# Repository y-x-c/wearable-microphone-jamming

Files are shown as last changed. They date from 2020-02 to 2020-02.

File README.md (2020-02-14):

# Wearable Microphone Jamming

<p align="center">teaser</p>

Repository for our paper [Wearable Microphone Jamming](http://sandlab.cs.uchicago.edu/jammer/).

This repo provides simulation source code, hardware design, firmware and schematics to replicate our results and prototypes in the paper.

## Structure of this repo

`simulation` contains MATLAB simulation code
- `doc`: documentation for the simulator
- `simulation.m`: main file of the simulator

`jammer_hardware_source` contains all sources related to hardware
- `3d_printing_models`: 3D model of our final prototype
- `arduino_code`: code for ATMEGA32U4 microprocessor, which controlls an AD9833 signal generator

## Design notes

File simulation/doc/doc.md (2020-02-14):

# Simulation Algorithm Documentation

[TOC]

## Simulation 

Details of our simulation can be found in the paper. Here, we expand and document its code, which we plan to release for future researchers to build upon.  

### Overview

Generally speaking, our simulation is a simple 3D ray tracing engine with a transducer-array placed at the origin (x=0,y=0,z=0). For a 3D location $p$, the mean sound pressure in a period of time, $\overline{P(p)}$, can be calculated as:

$$
\overline{P(p)} = \sqrt{ \frac{1}{|T|} \cdot \sum_{t \in T}{P_{t}(p)^2}}
$$

We sampled $0.4s$ with $0.013573s$ time step, which was intentionally chosen because it can not be divided by $1/fs$ (where $fs=25kHz$ in our case). $0.4s$ was chosen because it matches the speech rate in a conversation.

The total far field generated by all the transducers at time $t$ can be computed as the summation of the contribution of each indidvidual transducer
$$
P_t(p) = \sum_{s \in S}{P_{t,s}(p)}
$$

### Calculating $P_{t,s}(p)$

$$
P_{s,t}(p) = P_{ref} \cdot gain \cdot
               f_s(t - \frac{d(p, p_s)}{c_0})
$$

where $gain$ represents how the signal attenuate; $d(p, p_s)$ is the distance between the transducer and the point, and $f_s(t)$ represents the signal transmitted by a transducer $s$ at time $t$.

$P_{ref}$ is the reference pressure at 1m. We first measured sound pressure level at 1m and then use the following equation to calculate $P_{ref}$:

$$
P_{ref} = 10^{(L_A / 20)} * 0.00002\ Pa
$$

Here, $L_A=68dBA$ and $P_{ref} = 0.05024 \ Pa$.

### Calculating $gain$

$gain $ consists of 2 parts: (1) directivity of the transducer, (2) propagation loss with distance.

$$
gain = loss_{directivity} * loss_{distance}
$$

#### (1) Transducer directivity loss: $loss_{directivity}$

We model transducers as a piston source:

$$
loss_{directivity} = \frac{2 \cdot J_1(k \cdot r \cdot sin \theta)}{k \cdot r \cdot sin \theta}
$$

We also compared the directivity pattern from the datasheet with the one we modeled: (blue line means the modeled pattern, red line is the one from datasheet)

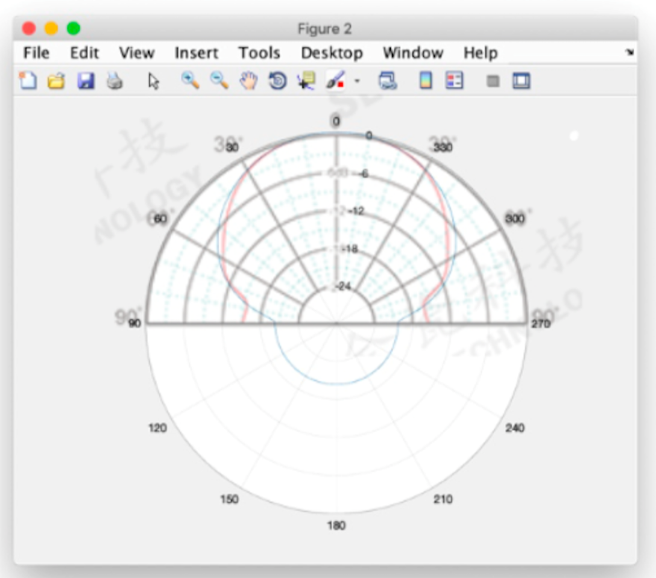
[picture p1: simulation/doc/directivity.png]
directivity


*For 90 to 270 degree, the original pattern is not available; we simply repeat the value at 90 degree at this range.*

#### (2) Propagation loss with distance: $loss_{distance}$

The propagation loss can be calculated as
$$
loss_{distance} = \frac{1}{d(p, p_s)}
$$

### Simulating rotation of a transducer array

Lastly, the previous explanation is how we simulate a static array. To add movement (e.g., rotation) to a transducer array, we do as follows: at each simulation step, a new position and orientation of a transducer is updated before calculating its resulting signal amplitude. For any given 3D location and transducer, its new position (and rotation) may increase or decrease $gain$, resulting in a stronger or weaker power. This rotation and its effects is how movement of a tranducer might assist in reducing blind spots.

## Running the simulator

To run our simulator, load our ``simulation_v3.m`` in MatLab (we used R2017b) and run it.

#### Exemplary simulation 

```matlab
xy_res = 0.002;

%%% To replicate the figures shown in nour simulation section in our paper, simply choose one of the options below (and comment the others)

%%% fig a 
num_sources = 1; rotate_angle = 0; planar_layout = 1;
simulation_v4;
%%% fig b 
num_sources = 1; rotate_angle = 0; planar_layout = 0;
simulation_v4;
%%% fig c 
num_sources = 9; rotate_angle = 0; planar_layout = 0;
simulation_v4;
%%% fig d 
num_sources = 1; rotate_angle = 15; planar_layout = 0;
simulation_v4;
```

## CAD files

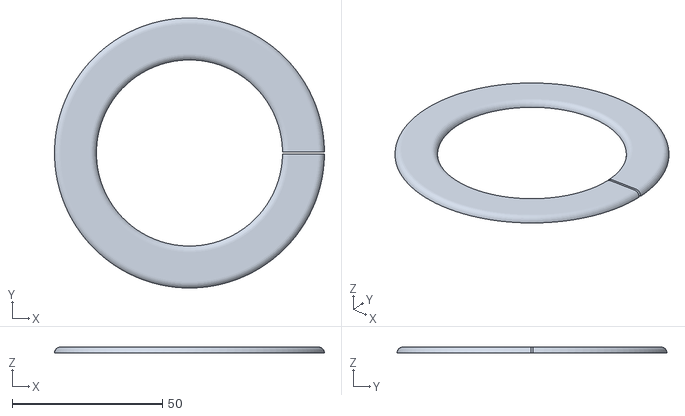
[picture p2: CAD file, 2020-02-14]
jammer_hardware_source/3d_printing_models/side_cap.stl
90.0 x 90.0 x 2.00

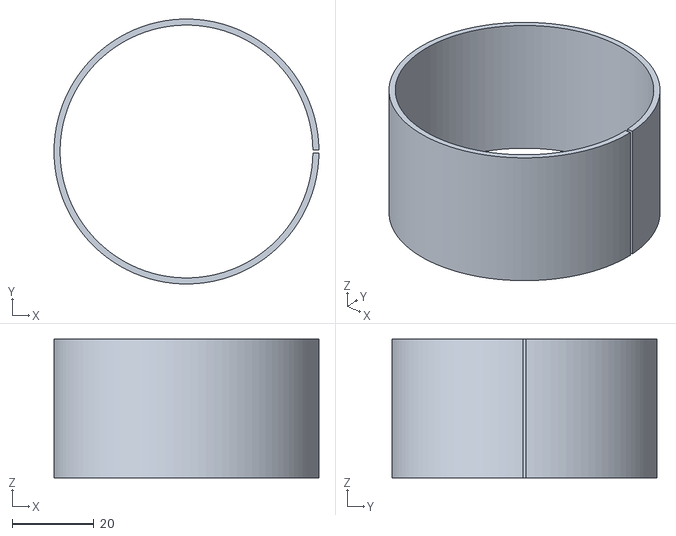
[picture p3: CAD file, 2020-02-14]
jammer_hardware_source/3d_printing_models/inner_ring.stl
65.0 x 65.0 x 34.0

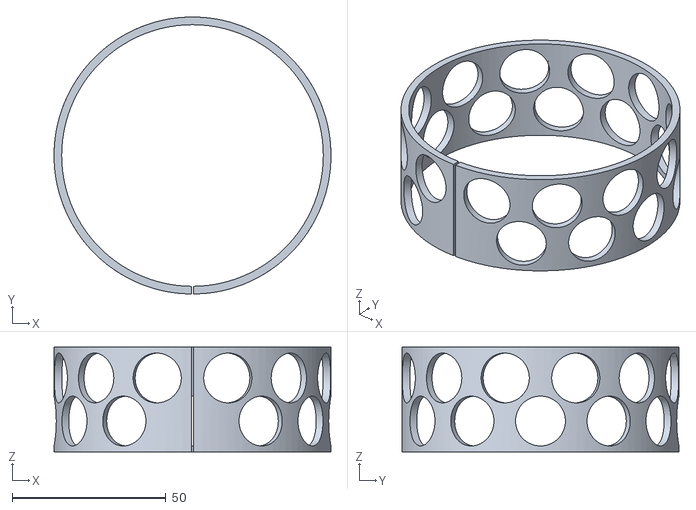
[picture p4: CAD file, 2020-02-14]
jammer_hardware_source/3d_printing_models/outer_ring.stl
90.0 x 90.0 x 34.0

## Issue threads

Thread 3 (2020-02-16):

About the hardware connection

SCWhite, 2020-02-16:
HI,
this project is amazing, good job.

Is there a chance showing the hardware connection ?
or how do the wave generator and ultrasonic transducer connect to each other?

It's truly fascinating work.

y-x-c, 2020-02-16:
Thanks!

The wave generator is connected to a 3w amplifier, and transducers are connected to the amplifier.
For the connection between the microprocessor and the wave generator, please refer to https://github.com/y-x-c/wearable-microphone-jamming/blob/1fd86c55f8f5f8a2b8336bd066d6a1fbe3146ac1/jammer_hardware_source/arduino_code/wearable_microphone_jammer/wea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

wissal12345, 2020-02-18:
merci

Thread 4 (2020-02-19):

Where can i buy nu25c16t?

vovo255, 2020-02-19:
Where can i buy nu25c16t? I rummaged through the entire Internet, I can not find anywhere. Where did you buy them?

fritztoch, 2020-02-19:
I believe there is an equivalent part TCRT16-40 which is available on AliExpress and Amazon.

vovo255, 2020-02-19:
But is it 40 kHz? This transmitter will suit you? You have 25 kHz.

SCWhite, 2020-02-20:
@vovo255
HI, I can confirm that 40kHz works jamming the mic (not sure the performance compare with 25kHz).
but you may need to change the code and some component.
may be try TCT25-16 ?

ozw1z5rd, 2020-02-23:
> Where can i buy nu25c16t? I rummaged through the entire Internet, I can not find anywhere. Where did you buy them?

You find them on eBay https://www.ebay.com/itm/16MM-Ultrasonic-Sensor-Probe-Transceiver-Receiver-TCT40-16T-R-NU25C16T-1-/272708217220

pracdaske, 2020-03-02:
@SCWhite I'm planning on recreate the device with a 40Khz transmitter. Which are those changes on the code that you mention to confirm that it worked with this frequencies.

T-vK, 2020-03-02:
That ebay offer is extremely expensive and includes the R-variant which is basically a microphone rather than a speaker. You'd pay like $63 for 23 of those.
You find much better offers on aliexpress. See #6

Scanboostar, 2020-05-11:
I found these:
https://nl.aliexpress.com/item/4000760514545.html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,searchweb201602_,searchweb201603_

pulpon6, 2023-04-20:
transmitter, receiver or transceiver 25Khz?

SCWhite, 2023-04-21:
in this case, you will just be using "transmit"
so transmitter and transceiver  should both work.

pulpon6, 2023-04-24:
And where can I buy nu25c16t ?

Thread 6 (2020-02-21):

Metrials and wiring all it up

digilander98, 2020-02-21:
Hi, is possible to have needed materials list amd wiring schematics?

Thabk you so much!

T-vK, 2020-02-25:
I've spent a lot of time on trying to figure out the exact hardware that was used and here is what i got so far:

1x [AD9833 DDS Signal Generator Module](https://www.aliexpress.com/item/33058314041.html)
23x [NU25C16T-1 aka TCT40-16T](https://www.aliexpress.com/item/32258563531.html)
1x [PAM8403 Mini Power Amplifier Board 3Wx2 (3-5.5V 4Ω)](https://www.droking.com/PAM8403-Power-amplifier-circuit-Board-Small-Audio-Amplifier-3W-3W-Digital-Amplifier-Board-Support-USB-Power-Supply)
1x [Adafruit Pro Trinket  (5V ATMEGA32U4)](https://www.adafruit.com/product/2000)
1x [500mAh 3.7V LiPo](https://www.aliexpress.com/item/33019024577.html) (seems close, but is not exactly the same)
1x [3.7v to 5v step up converter](https://www.aliexpress.com/item/32635991770.html) (seems close, but probably not the same)
1x [push button](https://www.aliexpress.com/item/33025135423.html) (The one with the blue tip; not 100% sure if it's the same)
1x blue LED with 220Ω resistor (not sure as you can only see the blue light in the video)

I think there's also a charging circuit and a charging port that hasn't been mentioned. At least it looks like there is something like a micro USB port in the video.
The charging circuit could be [something like this](https://www.aliexpress.com/item/32946628662.html).
But I'd probably ditch the step up converter for a [2 in 1 board like this](https://www.aliexpress.com/item/32819047141.html) that does both charging and stepping up to 5V. To save even more space you could desolder the USB A port.
Finally I would consider swapping the very pricey Adafruit Trinket for an [Arduino Micro clone](https://www.aliexpress.com/item/32768308647.html).

It would be great to have input from @y-x-c on all this because if we don't get the exact same components, they may not fit into the 3D printed enclosure. Thanks a lot for this awesome work btw!

digilander98, 2020-02-26:
Thank you sir

pracdaske, 2020-03-04:
@T-vK thanks a lot, I managed to get some modules that you listed as alternatives.

If you can could you provide some wiring schematics insights please

T-vK, 2020-03-04:
Once my parts arrive, I'll figure out how to wire them up and post my results here. But looking at the current situation in China, it may take more than a month until I receive my orders...

digilander98, 2020-03-04:
Why don t use an arduino nano clone?

digilander98, 2020-03-04:
And what about this:
https://a.aliexpress.com/_BOV2vj

SCWhite, 2020-03-05:
@T-vK
HI, I have a little question about
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

TCT40-16T have center frequency at 40kHz (on data sheet)
NU25C16T have center frequency at 25kHz

I doubt this two can be replace from each other (?)

I'm not a electronics expert, but I make some test on 40kHz transducer from a ultrasonic sensor
and it works fine to jam the microphone (with limit range about 10cm)

may be 40kHz doesn't have the same effect with 25kHz
 or may need to change the code from the project.

T-vK, 2020-03-05:
@digilanger98 I think the Arduino Micro clone is closer to the Trinket and I prefer micro USB over mini USB. Besides that, according to the paper the code was written for the ATMEGA32U, so it may not work on the nano.
What do you mean by "what about this"? It's the same board I linked to in my post, just a few cents cheaper.

@SCWhite I'm assuming they are the same because of offers like this:  https://www.ebay.com/itm/272708217220

But I could be wrong, that's why I was asking @y-x-c for input.

At what volume did you get a 10cm range btw? I think in the paper it was mentioned that it was running at almost 100 decibels.

digilander98, 2020-03-05:
For the arduino i think that the code is small and get right ports if different from the trinket will not be a huge problem.Differences from one arduino version to another are in size, clock mhz, memory space and ports capabilities. It seem to me that the nano can also do the job, i was wondering if you agree with that.For the board, in view i do not know more about that kind of chip but it seems little and without antenna plug, my question was intended to ask if it can be the same as per specs or not....Hope you can answer to my questionsThank you so much for your effortsIl 5 mar 2020 13:36, T-vK <notifications@github.com> ha scritto:@digilanger98 I think the Arduino Micro clone is closer to the Trinket and I prefer micro USB over mini USB. Besides that, according to the paper the code was written for the ATMEGA32U, so it may not work on the nano.
What do you mean by "what about this"? It's the same board I linked to in my post, just a few cents cheaper.
@SCWhite I'm assuming they are the same because of offers like this:  https://www.ebay.com/itm/272708217220
But I could be wrong, that's why I was asking @y-x-c for input.
At what volume did you get a 10cm range btw? I think in the paper it was mentioned that it was running at almost 100 decibels.

—You are receiving this because you authored the thread.Reply to this email directly, view it on GitHub, or unsubscribe.

T-vK, 2020-03-05:
Well, I just tried to compile and upload the code for the Arduino Nano and that sure worked fine. But I can't say if it works before I get my parts.
Now that I see the Nano next to the Micro, the Nano might not fit into the wristband though. It's like twice as thick dues to the PCB being double sided and due to the mini USB port being bigger and in addition to that, the board is like 1cm longer.

digilander98, 2020-03-05:
Waiting for parts me too....Il 5 mar 2020 15:56, T-vK <notifications@github.com> ha scritto:Well, I just tried to compile and upload the code for the Arduino Nano and that sure worked fine. But I can't say if it works before I get my parts.
Now that I see the Nano next to the Micro, the Nano might not fit into the wristband though. It's like twice as thick dues to the PCB being double sided and due to the mini USB port being bigger and in addition to that, the board is like 1cm longer.

—You are receiving this because you were mentioned.Reply to this email directly, view it on GitHub, or unsubscribe.

pracdaske, 2020-03-07:
Some colleagues and me managed to get the circuit going and disrupt the microphone of my phone while recording. We tested it with one transducer and I think we burned it because we put 5V across the circuit.
The wiring went something like this, nothing was welded just wired: USB to Arduino Pro Micro, Arduino to cheap signal generator (both power and instructions), cheap signal generator to amplifier (L input and goes to L+ output), amplifier to transducer HC-SR04 (We used a transducer that had transmitter and receiver, so we used the Trigger input only ). The amplifier and transducer were powered by a regulated outlet adapter through the 3.7 to 5V regulator. From this last pieces one was burn out and the other one runs hot, we will try to power everything through the Arduino.

This was in today's morning. Sadly we couldn't replicate it again 2 hours ago, we will weld pins to the holes of the modules and see if the problems was a the poor wiring connections.

Any insights on this would be appreciated. As you could tell we're a complete noobs at electronics so, yeah.

T-vK, 2020-03-07:
If I had to guess, I'd probably try something like this. But I'd check the outputs of the signal generator and the amplifier with an oscilloscope and multimeter first.
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

T-vK, 2020-03-09:
@pracdaske Just so you know, the HC-SR04 already has a signal generator and amplifier built in and the pinout doesn't give you access to its TCT40-16T or TCT40-16R. By specification you set the trigger pin high for 10 microseconds, then you set it low and then it sends eight short 40khz bursts in a row, which are then picked up by the TCT40-16R and converted into a high signal on the echo pin.
If you attach a 40khz signal generator amplified to 5v to the trigger, you're very close to the theoretical maximum where you almost don't trigger it anymore because the trigger pin needs to be high for at least 10μs.
My guess is the HC-SR04 is not designed to deal with such a crazy high amount of trigger pulses and it just overheated.
Also be aware that the module doesn't ever generate a continuous 40khz soundwave no matter what you do to the trigger pin. It will always only send 8 short bursts. That might be enough to interfere with a microphone, but it's not ideal.
Also, be aware that you probably shouldn't "power everything through the Arduino" because it can only provide very little current (e.g. 20mA on a digital pin and maybe 100mA or so on vcc+gnd). Drawing too much current will probably cause unexpected behavior, cause overheating, shutdowns or maybe even fry it.

digilander98, 2020-03-16:
Ok, think everyone will try to power from battery/usb recharge circuit the components at this point, once materials arrive....
Thank you so much guys!
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
gtaglia, 2020-11-21:
Hello does someone want to sell one working prototype? My email is gtaglia2012@yahoo.com

2br-2b, 2020-11-21:
I would also be interested in purchasing one!

sexycyborg, 2021-03-07:
If anyone would like, new tested PCB, BOM and files for PCBA service is here:
https://github.com/sexycyborg/Wearable-Audio-Jammer
Works quite well.

T-vK, 2021-03-07:
@sexycyborg Wow, that's amazing, thank you so much, you even put together a part list, which contains a link to the 25k transducer that was so difficult to find.
I just wanted to try that jlcpcb service you mentioned with your gerberfiles etc. Do they only print the PCB or do they also solder the components? It seems like they offer doing the soldering, but only for [one side](https://user-images.githubusercontent.com/11368523/110235249-49022580-7f2f-11eb-85f4-62e1022d0f47.jpg) ? I can select "Assemble top side" or "Asseble bottom side", but not both.

digilander98, 2021-06-28:
Hi, has anyone tryied tda2030a or pam8610 amplifiers that runs at 12v and outputs at least 10w?
Still do not figure out how can be hearing damage for a sound that we cannot hear....
Does anyone have more details about possible hearing loss when "hearing" sounds at those frequencies?

T-vK, 2021-06-28:
It's probably the sub-harmonics that damage your hearing in the end. For example you may not be able to hear a frequency of 25khz. But 25khz would have sub-harmonic frequencies of 12.5khz, 8.33khz, 6.25khz etc which at a certain volume will lead to hearing loss.
Also keep in mind that you could damage the hearing of animals like dogs that have a much wider range of frequencies they can hear.

digilander98, 2021-06-28:
@sexycyborg  Hi, sorry but i cannot figure out how you run your code in your wearable_microphone_jammer.ino ...
In particular do not understand when the MCP41010Write is called in the program and when "value" went assigned befor the call that i personally cannot see....
Sorry, maybe a lack in my knowledge, hope you can help me to understand....

pulpon6, 2023-04-25:
Hi community, I want to knwo if this model works for this project https://aliexpress.com/item/32867563228.html

SCWhite, 2023-04-25:
> Hi community, I want to knwo if this model works for this project https://aliexpress.com/item/32867563228.html

yeah, I think it will do the job.
just remember to use the "T25"  (supposed to be "Transmit" ?)

pulpon6, 2023-04-27:
@SCWhite @T-vK How many distances will be blocked if I use 10 T25?

SCWhite, 2023-04-28:
@pulpon6  well, that's a question with no simple answer.
really depends on the environment / transmit power / setup / the definition of "blocked" etc.
but I'll say maybe 3 meter

And just a weird thought.
if you promise to share your work and project
I think I can dive into my old laptop and search for more test I've done.
(though I'm not sure those data will be useful to you, but I do make some modify to make it stronger)

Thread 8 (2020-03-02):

PAM8403 filter

lmadden1, 2020-03-02:
I have been playing with the frequency generator and the PAM8403. Do you add any low pass filtering  to the PAM8403 Class D before feeding the ultrasonic transducer?  Also, like other contributors I am having difficulty finding a 25kHz  transducer, do you believe 40kHz will work? Any changes to the design as a result?
thanks /liam

T-vK, 2020-03-20:
Personally, I didn't get very good results with a 40khz transducer. I haven't received my 25khz transducers yet so I can't really compare the two.
All I can say is that with a 3W amplifier at max volume I get a little less than 1 meter of range.
I can't say if my transducer is already running at more than 100db (which could cause permanent hearing loss btw) or if it's actually only running at 60db and I just need a bigger amplifier.

You might wanna read through this issue: https://github.com/y-x-c/wearable-microphone-jamming/issues/6

I'm also currently working on a simpler design that doesn't require an external signal generator. You can find the wiring diagram, parts list and code here: https://github.com/T-vK/alexa-jammer#how-to-use-the-mic-jammer

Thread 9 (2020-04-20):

Step-by-step instructions?

2br-2b, 2020-04-20:
Hello!

Are there any step-by-step instructions that I could follow as someone who doesn't have that much experience with electrical engineering to make one of these for myself?

T-vK, 2020-04-20:
Have you looked at thw other issues? For example: https://github.com/y-x-c/wearable-microphone-jamming/issues/6#issuecomment-596074096a

It really just is a matter of soldering everything together and then open the ino file of this project with your Arduino IDE and upload it to your Arduino with a click of one button.
Just give it a try and if you get stuck I'm sure we can help you.

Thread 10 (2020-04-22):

Pacemakers?

BoneOctopus, 2020-04-22:
Hey!
First off, super cool project. I just wanted to ask if there was any known issues with this product and pacemakers, as ultrasonic sound can mess with specific kinds.

T-vK, 2020-04-22:
I doubt that any pacemakers would be affected by any kind of ultrasonic noise at < 100 decibels.
I mean we are surrounded by ultrasonic noise every day. I mean just think about all the electronic devices in your house: https://en.wikipedia.org/wiki/Electromagnetically_induced_acoustic_noise
Or what about dog whistles? Do you think a pacemaker would be approved if it would be affected by stuff like that? Seems unlikely to me.

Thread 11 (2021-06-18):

Does not work with iphone 8 and above

Europe-Connection, 2021-06-18:
Hello, the system works fine with all phones except iphones 8 and above, could someone explain to me why and how to fix it?

digilander98, 2021-06-21:
Membrane water protected mic....hard to found a solution without tiying to go high with db...Il 18 giu 2021 20:44, Europe-Connection ***@***.***> ha scritto:
Hello, the system works fine with all phones except iphones 8 and above, could someone explain to me why and how to fix it?

—You are receiving this because you are subscribed to this thread.Reply to this email directly, view it on GitHub, or unsubscribe.

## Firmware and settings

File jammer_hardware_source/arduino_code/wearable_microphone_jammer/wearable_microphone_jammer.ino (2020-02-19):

/*
    wearable microphone jammer
    --------
    This is the code for 
    Circuit buildup and wiring explanation added in comments by Steven Nagels and Shan-Yuan Teng.
   
    HARDWARE
    --------
    - Pro Trinket 5V board. https://www.adafruit.com/product/2000
    - AD9833 Waveform Module https://www.amazon.com/gp/product/B076LF3LFC
   
    CONNECTION
    --------
    AD9833 PCB to Pro Trinket board:
    DAT --> pin 11 (MOSI) [note: pin 12 is MISO]
    CLK --> pin 13 (SCK)
    FSY --> pin A0 (AD9833 SS)
    CS --> pin A1 (MCP41010i SS)
    
    AD9833 PCB OVERVIEW
    --------
    PCB has following INPUTS (in order): CS, DAT, CLK, FSY, GND, VCC
                  and OUTPUTS (in order): GND, PGA, (footprint for SMA connector), VOUT, GND

    LOOKING AT PCB WITH INPUTS FACING YOU: left side = PGA, right side = waveform generator

    (left side)
    PGA stands for Programmable Gain Amplifier and is constructed of a MCP41010i digital potentiometer (addressed via SPI)
    and an AD8051 high speed operational amplifier. By changing the MCP41010i resistance value, you set the amplifier's gain.
    The SMA connector footprint also connects to the PGA output.

    MCP41010i is on the SPI bus, thus has a shared connection to DAT and CLK with the AD9833. Its chip select is the CS input.

    MCP41010i datasheet: http://ww1.microchip.com/downloads/en/devicedoc/11195c.pdf
    AD8051 datasheet: https://www.analog.com/media/en/technical-documentation/data-sheets/AD8051_8052_8054.pdf

    (right side)
    A large 25 MHz xtal on top half of board. It determines the reference frequency used in the code below. AD9833 situated
    on bottom half of board. This part is completely controlled via SPI.

    AD9833 is on the SPI bus, thus has a shared connection to DAT and CLK with the MCP41010i. Its chip select is the FSY input.

    AD9833 datasheet: https://www.analog.com/media/en/technical-documentation/data-sheets/AD9833.pdf
*/

/*
   ApplySignal.ino
   2018 WLWilliams

   This sketch demonstrates the basic use of the AD9833 DDS module library.
   Using the ApplySignal to generate and/or change the signal.

   This program is free software: you can redistribute it and/or modify it under
   the terms of the GNU General Public License as published by the Free Software Foundation,
   either version 3 of the License, or (at your option) any later version.
   This program is distributed in the hope that it will be useful, but WITHOUT ANY WARRANTY;
   without even the implied warranty of MERCHANTABILITY or FITNESS FOR A PARTICULAR PURPOSE.
   See the GNU General Public License for more details. You should have received a copy of
   the GNU General Public License along with this program.
   If not, see <http://www.gnu.org/licenses/>.

   This example code is in the public domain.

   Library code found at: https://github.com/Billwilliams1952/AD9833-Library-Arduino
*/

#include "AD9833.h"

#define FNC_PIN A0
#define SEL_PIN A1

int gen_freq = 25000;

int RXLED = 17;  // The RX LED has a defined Arduino pin

//--------------- Create an AD9833 object ----------------
// Note, SCK and MOSI must be connected to CLK and DAT pins on the AD9833 for SPI
AD9833 gen(FNC_PIN);       // Defaults to 25MHz internal reference frequency

void setup() {
  //start gen
  gen.Begin();
  pinMode(SEL_PIN, OUTPUT);
  //set gen to SINE
  gen.ApplySignal(SINE_WAVE, REG0, gen_freq);
  //start gens
  gen.EnableOutput(true);
  //put both PGAs at max output
  MCP41010Write(255, SEL_PIN);
  SPI.setDataMode(SPI_MODE2);
}

void loop() {
  gen.ApplySignal(SINE_WAVE, REG0, random(24000, 26000));
  MCP41010Write(255, SEL_PIN);
}

//  function below adapted from http://henrysbench.capnfatz.com/henrys-bench/arduino-output-devices/mcp41010-digital-potentiometer-arduino-user-manual/
//  8bit value to write --> 256 levels --> value 0 to 255
void MCP41010Write(byte value, int CS)
{
  SPI.setDataMode(SPI_MODE0);
  // Note that the integer vale passed to this subroutine
  // is cast to a byte
  digitalWrite(CS, LOW);
  SPI.transfer(B00010001); // This tells the chip to set the pot
  SPI.transfer(value);     // This tells it the pot position
  digitalWrite(CS, HIGH);
}

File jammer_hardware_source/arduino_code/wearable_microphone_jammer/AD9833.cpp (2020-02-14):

/*
 * AD9833.cpp
 * 
 * Copyright 2016 Bill Williams <wlwilliams1952@gmail.com, github/BillWilliams1952>
 *
 * Thanks to john@vwlowen.co.uk for his work on the AD9833. His web page
 * is: http://www.vwlowen.co.uk/arduino/AD9833-waveform-generator/AD9833-waveform-generator.htm
 * 
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
 */

#include "AD9833.h"

/*
 * Create an AD9833 object
 */
AD9833 :: AD9833 ( uint8_t FNCpin, uint32_t referenceFrequency ) {
	// Pin used to enable SPI communication (active LOW)--> MARKED FSY on board
#ifdef FNC_PIN
	pinMode(FNC_PIN,OUTPUT);
#else
	this->FNCpin = FNCpin;
	pinMode(FNCpin,OUTPUT);
#endif
	WRITE_FNCPIN(HIGH);

	/* TODO: The minimum resolution and max frequency are determined by
	 * by referenceFrequency. We should calculate these values and use
	 * them during setFrequency. The problem is if the user programs a
	 * square wave at refFrequency/2, then changes the waveform to sine.
	 * The sine wave will not have enough points?
	 */
	refFrequency = referenceFrequency;
	
	// Setup some defaults
	DacDisabled = false;
	IntClkDisabled = false;
	outputEnabled = false;
	waveForm0 = waveForm1 = SINE_WAVE;
	frequency0 = frequency1 = 1000;		// 1 KHz sine wave to start
	phase0 = phase1 = 0.0;				// 0 phase
	activeFreq = REG0; activePhase = REG0;
}

/*
 * This MUST be the first command after declaring the AD9833 object
 * Start SPI and place the AD9833 in the RESET state
 */
void AD9833 :: Begin ( void ) {
	SPI.begin();
	delay(100);
	Reset();	// Hold in RESET until first WriteRegister command
}

/*
 * Setup and apply a signal. phaseInDeg defaults to 0.0 if not supplied.
 * phaseReg defaults to value of freqReg if not supplied.
 * Note that any previous calls to EnableOut,
 * SleepMode, DisableDAC, or DisableInternalClock remain in effect.
 */
void AD9833 :: ApplySignal ( WaveformType waveType,
		Registers freqReg, float frequencyInHz,
		Registers phaseReg, float phaseInDeg ) {
	SetFrequency ( freqReg, frequencyInHz );
	SetPhase ( phaseReg, phaseInDeg );
	SetWaveform ( freqReg, waveType );
	SetOutputSource ( freqReg, phaseReg );
}

/***********************************************************************
						Control Register
------------------------------------------------------------------------
D15,D14(MSB)	10 = FREQ1 write, 01 = FREQ0 write,
 				11 = PHASE write, 00 = control write
D13	If D15,D14 = 00, 0 = individual LSB and MSB FREQ write,
 					 1 = both LSB and MSB FREQ writes consecutively
	If D15,D14 = 11, 0 = PHASE0 write, 1 = PHASE1 write
D12	0 = writing LSB independently
 	1 = writing MSB independently
D11	0 = output FREQ0,
	1 = output FREQ1
D10	0 = output PHASE0
	1 = output PHASE1
D9	Reserved. Must be 0.
D8	0 = RESET disabled
	1 = RESET enabled
D7	0 = internal clock is enabled
	1 = internal clock is disabled
D6	0 = onboard DAC is active for sine and triangle wave output,
 	1 = put DAC to sleep for square wave output
D5	0 = output depends on D1
	1 = output is a square wave
D4	Reserved. Must be 0.
D3	0 = square wave of half frequency output
	1 = square wave output
D2	Reserved. Must be 0.
D1	If D5 = 1, D1 = 0.
	Otherwise 0 = sine output, 1 = triangle output
D0	Reserved. Must be 0.
***********************************************************************/

/*
 * Hold the AD9833 in RESET state.
 * Resets internal registers to 0, which corresponds to an output of
 * midscale - digital output at 0.
 * 
 * The difference between Reset() and EnableOutput(false) is that
 * EnableOutput(false) keeps the AD9833 in the RESET state until you
 * specifically remove the RESET state using EnableOutput(true).
 * With a call to Reset(), ANY subsequent call to ANY function (other
 * than Reset itself and Set/IncrementPhase) will also remove the RESET
 * state.
 */
void AD9833 :: Reset ( void ) {
	WriteRegister(RESET_CMD);
	delay(15);
}

/*
 *  Set the specified frequency register with the frequency (in Hz)
 */
void AD9833 :: SetFrequency ( Registers freqReg, float frequency ) {
	// TODO: calculate max frequency based on refFrequency.
	// Use the calculations for sanity checks on numbers.
	// Sanity check on frequency: Square - refFrequency / 2
	//							  Sine/Triangle - refFrequency / 4
	if ( frequency > 12.5e6 )	// TODO: Fix this based on refFreq
		frequency = 12.5e6;
	if ( frequency < 0.0 ) frequency = 0.0;
	
	// Save frequency for use by IncrementFrequency function
	if ( freqReg == REG0 ) frequency0 = frequency;
	else frequency1 = frequency;
	
	int32_t freqWord = (frequency * pow2_28) / (float)refFrequency;
	int16_t upper14 = (int16_t)((freqWord & 0xFFFC000) >> 14), 
			lower14 = (int16_t)(freqWord & 0x3FFF);

	// Which frequency register are we updating?
	uint16_t reg = freqReg == REG0 ? FREQ0_WRITE_REG : FREQ1_WRITE_REG;
	lower14 |= reg;
	upper14 |= reg;   

	// I do not reset the registers during write. It seems to remove
	// 'glitching' on the outputs.
	WriteControlRegister();
	// Control register has already been setup to accept two frequency
	// writes, one for each 14 bit part of the 28 bit frequency word
	WriteRegister(lower14);			// Write lower 14 bits to AD9833
	WriteRegister(upper14);			// Write upper 14 bits to AD9833
}

/*
 * Increment the specified frequency register with the frequency (in Hz)
 */
void AD9833 :: IncrementFrequency ( Registers freqReg, float freqIncHz ) {
	// Add/subtract a value from the current frequency programmed in
	// freqReg by the amount given
	float frequency = (freqReg == REG0) ? frequency0 : frequency1;
	SetFrequency(freqReg,frequency+freqIncHz);
}

/*
 * Set the specified phase register with the phase (in degrees)
 * The output signal will be phase shifted by 2π/4096 x PHASEREG
 */
void AD9833 :: SetPhase ( Registers phaseReg, float phaseInDeg ) {
	// Sanity checks on input
	phaseInDeg = fmod(phaseInDeg,360);
	if ( phaseInDeg < 0 ) phaseInDeg += 360;
	
	// Phase is in float degrees ( 0.0 - 360.0 )
	// Convert to a number 0 to 4096 where 4096 = 0 by masking
	uint16_t phaseVal = (uint16_t)(BITS_PER_DEG * phaseInDeg) & 0x0FFF;
	phaseVal |= PHASE_WRITE_CMD;
	
	// Save phase for use by IncrementPhase function
	if ( phaseReg == REG0 )	{
		phase0 = phaseInDeg;
	}
	else {
		phase1 = phaseInDeg;
		phaseVal |= PHASE1_WRITE_REG;
	}
	WriteRegister(phaseVal);
}

/*
 * Increment the specified phase register by the phase (in degrees)
 */
void AD9833 :: IncrementPhase ( Registers phaseReg, float phaseIncDeg ) {
	// Add/subtract a value from the current phase programmed in
	// phaseReg by the amount given
	float phase = (phaseReg == REG0) ? phase0 : phase1;
	SetPhase(phaseReg,phase + phaseIncDeg);
}

/*
 * Set the type of waveform that is output for a frequency register
 * SINE_WAVE, TRIANGLE_WAVE, SQUARE_WAVE, HALF_SQUARE_WAVE
 */
void AD9833 :: SetWaveform (  Registers waveFormReg, WaveformType waveType ) {
	// TODO: Add more error checking?
	if ( waveFormReg == REG0 )
		waveForm0 = waveType;
	else
		waveForm1 = waveType;
	WriteControlRegister();
}
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

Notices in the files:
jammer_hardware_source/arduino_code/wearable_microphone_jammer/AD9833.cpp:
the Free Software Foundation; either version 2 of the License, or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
